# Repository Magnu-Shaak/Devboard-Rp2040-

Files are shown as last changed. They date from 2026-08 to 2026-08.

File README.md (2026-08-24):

# Devboard-Rp2040-

This is a devboard following the Kai Pereira tutorial. However, there are 2 major differences:
- 1: Mine breaks out all pins while following the Pi-Pico layout*(mostly). He followed the Pi-Pico layout too*, but I also added 2 1x2 connectors which I used to break out the final GPIO pin, and provide easy access to 3v3 and VBUS from the bottom of the board. This greatly benefits the left side, as it now has an ADC pin and power access from the bottom, instead of needing to run traces to the other side of the board. And despite moving the 3 pin connector (used for debugging) up, some Pi Pico boards have it in the center anyways, so this doesn't make in incompatible as a drop in replacement either(unless its battery operated).
- 2: I also have opted to use the higher power rated LDO for my 3v3 line, whereas he swapped to a lower power rated one for space. Just better overall.

I made these changes for convenience. Having a better LDO is generally just better and the ADC and power pin breakouts are really convenient and help reduce congestion below the chip.

*Replaced some unused i/o pins (VSYS, 3v3_EN, ADC_REF) to breakout some 3 more GPIO pins

## For Reproducing
If you are recreating this yourself, look at the Readme in production for more information.

BOM:
| Item |  Quantity | Listed Price | Total Cost [for me]  (shipping, sales tax) | Link | Source  | Notes |
|---|---|---|---|---|---|---|
| PCB | 5 | 2 | 2 | https://cart.jlcpcb.com/shopcart/cart | JLCPCB  | $2 deal |
| PCBA | 2 | 33.13 | 33.13 | https://cart.jlcpcb.com/shopcart/cart | JLCPCB  | |
| Custom Duties & Taxes | | 12.24 | 12.24 | https://cart.jlcpcb.com/shopcart/cart | JLCPCB  | US Customs |
| JLC Shipping (DDP) | | 29.98 | 29.98 | https://cart.jlcpcb.com/shopcart/cart | JLCPCB  | UPS Express (DDP)  |
| SMT PCBA Coupon | | -10 | -10 | https://cart.jlcpcb.com/shopcart/cart | JLC PCB | New Account Coupon |
| | | | | https://cart.jlcpcb.com/shopcart/cart | | |
| Total | 7 | 67.35 | 67.35 | https://excel.cloud.microsoft/en-us | | |

The extra connectors I added:



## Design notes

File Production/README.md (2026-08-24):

Creating Production folder

- Unzipped gerbers are under PCB

## For Production:

If you are RECREATING yourself, you need to EDIT the CPL FILE:
- U2: set rotation to 90*
- U3: set rotation to 270*
- J1: decrease Mid Y by 1.4605 mm

The files here are already edited, if you are having probelems.

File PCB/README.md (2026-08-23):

Creating PCB folder

 - Zipped gerbers are under Production

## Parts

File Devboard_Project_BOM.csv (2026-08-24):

Item | Quantity | Listed Price | Total Cost [for me] (shipping, sales tax) | Link | Source | Notes
PCB | 5 | 2 | 2 | https://cart.jlcpcb.com/shopcart/cart | JLCPCB | $2 deal
PCBA | 2 | 33.13 | 33.13 | https://cart.jlcpcb.com/shopcart/cart | JLCPCB
Custom Duties & taxes |  | 12.24 | 12.24 |  | JLCPCB | US Customs
JLC Shipping (DDP) |  | 29.98 | 29.98 |  | JLCPCB | UPS Express (DDP)
SMT PCBA Coupon |  | -10 | -10 |  | JLC PCB | New Account Coupon
Total | 7 | 67.35 | 67.35

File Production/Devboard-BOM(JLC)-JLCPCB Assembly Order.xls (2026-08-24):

JLCPCB BOM Tool - BOM Matching
BOM name：Devboard-BOM(JLC)-JLCPCB Assembly Order.xlsx |  |  | Download Time：2026-08-24 10:50:31 |  |  |  | * Our matching results are updated in real-time, but stock and prices may change. If it's been over 24 hours, please re-match before placing your order.
PCB Assembled Qty：5 |  |  | Est. Total Price：6.7236
Your BOM |  |  |  | Matched Parts |  |  |  |  |  |  | Order Information
Designator | Comment | Footprint | JLCPCB Part # | Matches | Part # | Manufacturer | Footprint | Description | Category | Warning | JLCPCB Part # | Product link | Lib Type | Qty | Source | Total Price ($)
C1,C10 | 1uF | Capacitor_SMD:C_0402_1005Metric |  | Select by System | CL05A105KA5NQNC | Samsung Electro-Mechanics | 0402 | 1uF 25V X5R ±10% 0402 Multilayer Ceramic Capacitors MLCC - SMD/SMT ROHS | Multilayer Ceramic Capacitors MLCC - SMD/SMT |  | C52923 | https://jlcpcb.com/partdetail/53938-CL05A105KA5NQNC/C52923 | Basic | 4 | 4 JLCPCB | 0.0484
C2,C3,C4,C5,C6,C7,C8,C9,C11,C12,C17 | 0.1uF | Capacitor_SMD:C_0402_1005Metric |  | Select by System | CL05B104KO5NNNC | Samsung Electro-Mechanics | 0402 | 100nF 16V X7R ±10% 0402 Multilayer Ceramic Capacitors MLCC - SMD/SMT ROHS | Multilayer Ceramic Capacitors MLCC - SMD/SMT |  | C1525 | https://jlcpcb.com/partdetail/1877-CL05B104KO5NNNC/C1525 | Basic | 22 | 22 JLCPCB | 0.121
C13,C14 | 10uF | Capacitor_SMD:C_0603_1608Metric |  | Select by System | CL10A106KP8NNNC | Samsung Electro-Mechanics | 0603 | 10V 10uF X5R ±10% 0603 Multilayer Ceramic Capacitors MLCC - SMD/SMT ROHS | Multilayer Ceramic Capacitors MLCC - SMD/SMT |  | C19702 | https://jlcpcb.com/partdetail/20411-CL10A106KP8NNNC/C19702 | Basic | 4 | 4 JLCPCB | 0.1452
C15,C16 | 33pF | Capacitor_SMD:C_0402_1005Metric |  | Select by System | 0402CG330J500NT | FH (Guangdong Fenghua Advanced Tech) | 0402 | 33pF 50V C0G ±5% 0402 Multilayer Ceramic Capacitors MLCC - SMD/SMT ROHS | Multilayer Ceramic Capacitors MLCC - SMD/SMT |  | C1562 | https://jlcpcb.com/partdetail/1914-0402CG330J500NT/C1562 | Basic | 4 | 4 JLCPCB | 0.0228
J1 | USB_C_Receptacle_USB2.0_14P | Connector_USB:USB_C_Receptacle_HRO_TYPE-C-31-M-12 |  | Select by System | TYPE-C-31-M-12 | Korean Hroparts Elec | SMD | -30℃~+80℃ 1 10,000 cycles 16P 20V 5A 7.35mm Female Surface Mount, Right Angle Type-C SMD USB Connectors ROHS | USB Connectors |  | C165948 | https://jlcpcb.com/partdetail/Korean_HropartsElec-TYPE_C_31_M12/C165948 | Extended | 2 | 2 JLCPCB | 0.371
J2,J3 | Conn_01x20 | Connector_PinHeader_2.54mm:PinHeader_1x20_P2.54mm_Vertical |  | Select by System | 2.54-1*20P直针 | BOOMELE(Boom Precision Elec) | 插件,P=2.54mm | -40℃~+105℃ 1 1x20P 2.54mm 20P 3A Black Brass Pin Header Through Hole 插件,P=2.54mm Pin Headers ROHS | Pin Headers |  | C50981 | https://jlcpcb.com/partdetail/51993-2_54_1_20P/C50981 | Extended | 0 | 0 JLCPCB | 0
J4 | Conn_01x03 | Connector_PinHeader_2.54mm:PinHeader_1x03_P2.54mm_Vertical |  | Select by System | 1.27-1*3P针 | BOOMELE(Boom Precision Elec) | 插件,P=1.27mm | -55℃~+105℃ 1 1.27mm 1.7mm 1x3P 2.5mm 3A 3P 3mm Black Brass Pin Header Through Hole 插件,P=1.27mm Pin Headers ROHS | Pin Headers |  | C24980 | https://jlcpcb.com/partdetail/25717-1_27_1_3P/C24980 | Extended | 0 | 0 JLCPCB | 0
J5,J6 | Conn_01x02 | Connector_PinHeader_2.54mm:PinHeader_1x02_P2.54mm_Vertical |  | Select by System | PZ254V-11-02P | XFCN | 插件,P=2.54mm | -40℃~+105℃ 1 1x2P 2.54mm 2.5mm 250V 2P 3A 3mm 6mm Black Brass Pin Header Through Hole 插件,P=2.54mm Pin Headers ROHS | Pin Headers |  | C492401 | https://jlcpcb.com/partdetail/XFCN-PZ254V_1102P/C492401 | Extended | 0 | 0 JLCPCB | 0
R1,R2 | 5.1K | Resistor_SMD:R_0402_1005Metric |  | Select by System | 0402WGF5101TCE | UNI-ROYAL(Uniroyal Elec) | 0402 | -55℃~+155℃ 5.1kΩ 50V 62.5mW Thick Film Resistor ±1% ±100ppm/℃ 0402 Chip Resistor - Surface Mount ROHS | Chip Resistor - Surface Mount |  | C25905 | https://jlcpcb.com/partdetail/26648-0402WGF5101TCE/C25905 | Basic | 4 | 4 JLCPCB | 0.0172
R3,R4 | 27 | Resistor_SMD:R_0402_1005Metric |  | Select by System | 0402WGF270JTCE | UNI-ROYAL(Uniroyal Elec) | 0402 | -55℃~+155℃ 27Ω 50V 62.5mW Thick Film Resistor ±1% ±100ppm/℃ 0402 Chip Resistor - Surface Mount ROHS | Chip Resistor - Surface Mount |  | C25100 | https://jlcpcb.com/partdetail/25843-0402WGF270JTCE/C25100 | Extended | 20 | 20 JLCPCB | 0.064
R5,R6 | 1K | Resistor_SMD:R_0402_1005Metric |  | Select by System | 0402WGF1001TCE | UNI-ROYAL(Uniroyal Elec) | 0402 | -55℃~+155℃ 1kΩ 50V 62.5mW Thick Film Resistor ±1% ±100ppm/℃ 0402 Chip Resistor - Surface Mount ROHS | Chip Resistor - Surface Mount |  | C11702 | https://jlcpcb.com/partdetail/12256-0402WGF1001TCE/C11702 | Basic | 4 | 4 JLCPCB | 0.0268
R7 | 10K | Resistor_SMD:R_0402_1005Metric |  | Select by System | 0402WGF1002TCE | UNI-ROYAL(Uniroyal Elec) | 0402 | -55℃~+155℃ 10kΩ 50V 62.5mW Thick Film Resistor ±1% ±100ppm/℃ 0402 Chip Resistor - Surface Mount ROHS | Chip Resistor - Surface Mount |  | C25744 | https://jlcpcb.com/partdetail/26487-0402WGF1002TCE/C25744 | Basic | 2 | 2 JLCPCB | 0.0038
SW1 | SW_Push | Button_Switch_SMD:SW_Push_SPST_NO_Alps_SKRK |  | Select by System | TS-1088-AR02016 | XUNPU | SMD,4x3mm | -30℃~+80℃ 1.6N 100,000 cycles 12V 2mm 3.9mm 3mm 50mA Black Round Button SMD(SMT) Tab SPST Surface Mount,Vertical Without Bracket SMD,4x3mm Tactile Switches ROHS | Tactile Switches |  | C720477 | https://jlcpcb.com/partdetail/XUNPU-TS_1088AR02016/C720477 | Basic | 2 | 2 JLCPCB | 0.1112
U1 | RP2040 | Package_DFN_QFN:QFN-56-1EP_7x7mm_P0.4mm_EP3.2x3.2mm |  | Select by System | RP2040 | Raspberry Pi | LQFN-56(7x7) | 12bit 133MHz 30 LQFN-56(7x7) Microcontrollers (MCU/MPU/SOC) ROHS | Microcontrollers (MCU/MPU/SOC) |  | C2040 | https://jlcpcb.com/partdetail/RaspberryPi-RP2040/C2040 | Extended | 2 | 2 JLCPCB | 1.9846
U2 | NCP1117-3.3_SOT223 | Package_TO_SOT_SMD:SOT-223-3_TabPin2 |  | Select by System | NCP1117ST33T3G | onsemi | SOT-223 | 0.003%Vout 0℃~+125℃@(Ta) 1 1.2V@(800mA) 1A 20V 3.3V 62dB@(120Hz) 6mA Fixed Over Current Protection、Thermal Shutdown Positive SOT-223 Voltage Regulators - Linear, Low Drop Out (LDO) Regulators ROHS | Voltage Regulators - Linear, Low Drop Out (LDO) Regulators |  | C26537 | https://jlcpcb.com/partdetail/onsemi-NCP1117ST33T3G/C26537 | Extended | 2 | 2 JLCPCB | 0.4708
U3 | W25Q16JVUXIQTR | Package_SON:Winbond_USON-8-1EP_3x2mm_P0.5mm_EP0.2x1.6mm |  | Select by System | W25Q16JVUXIQ | Winbond Elec | USON-8-EP(2x3) | -40℃~+85℃ 100,000 cycles 10uA 133MHz 16Mbit 2.7V~3.6V 20 Years 3ms SPI USON-8-EP(2x3) NOR FLASH ROHS | NOR FLASH |  | C2843335 | https://jlcpcb.com/partdetail/WinbondElec-W25Q16JVUXIQ/C2843335 | Extended | 2 | 2 JLCPCB | 3.1474
Y1 | 12MHz | Crystal:Crystal_SMD_3225-4Pin_3.2x2.5mm |  | Select by System | X322512MSB4SI | YXC Crystal Oscillators | SMD3225-4P | -40℃~+85℃ 12MHz 20pF 80Ω Crystal Oscillator ±10ppm ±20ppm SMD3225-4P Crystals ROHS | Crystals |  | C9002 | https://jlcpcb.com/partdetail/YXC_CrystalOscillators-X322512MSB4SI/C9002 | Basic | 2 | 2 JLCPCB | 0.1894

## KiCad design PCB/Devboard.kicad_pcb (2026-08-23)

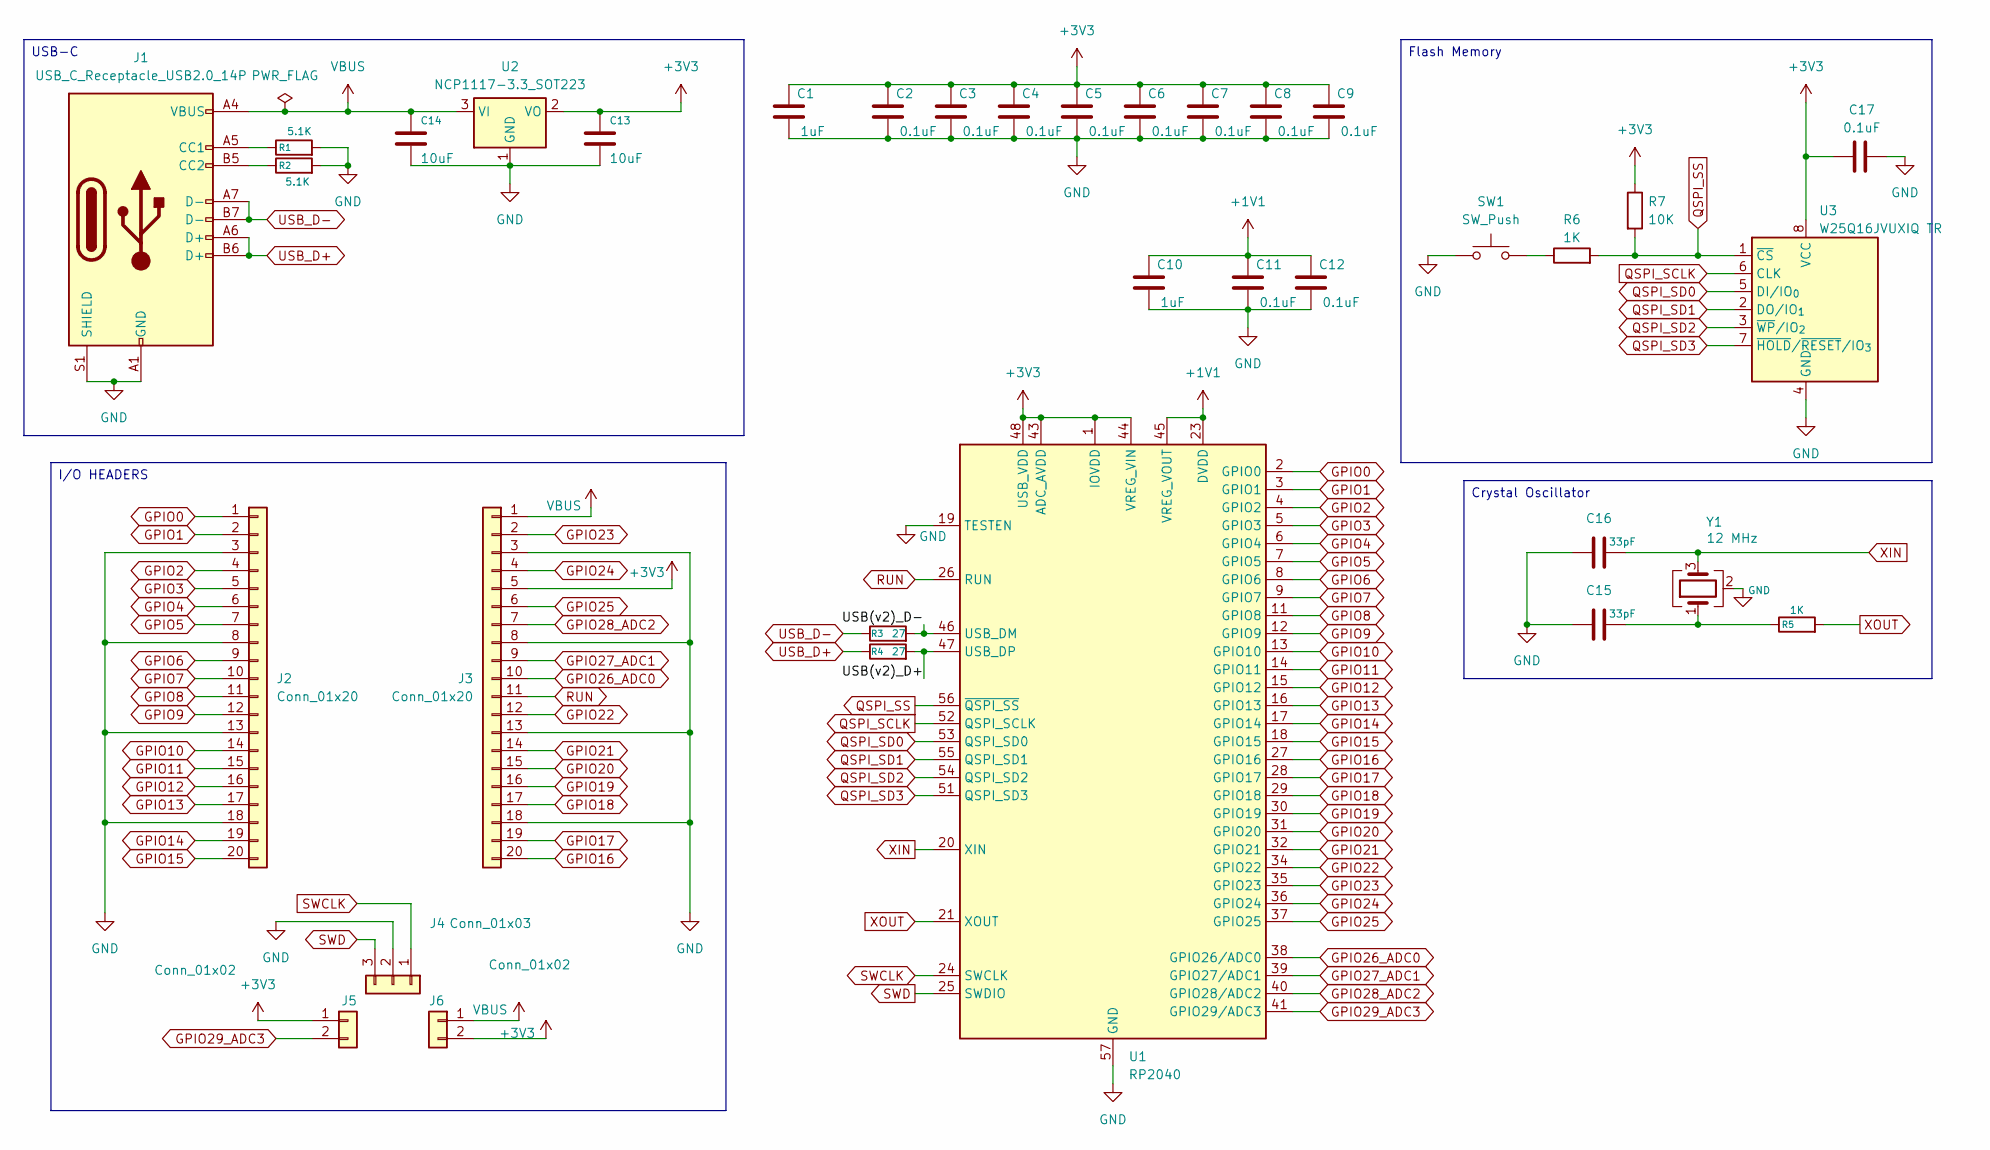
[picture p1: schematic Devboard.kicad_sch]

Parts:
C1, C10: 1uF; C_0402_1005Metric
C2, C3, C4, C5, C6, C7, C8, C9, C11, C12, C17: 0.1uF; C_0402_1005Metric
C13, C14: 10uF; C_0603_1608Metric
C15, C16: 33pF; C_0402_1005Metric
J1: USB_C_Receptacle_USB2.0_14P; USB_C_Receptacle_HRO_TYPE-C-31-M-12
J2, J3: Conn_01x20; PinHeader_1x20_P2.54mm_Vertical
J4: Conn_01x03; PinHeader_1x03_P2.54mm_Vertical
J5, J6: Conn_01x02; PinHeader_1x02_P2.54mm_Vertical
R1, R2: 5.1K; R_0402_1005Metric
R3, R4: 27; R_0402_1005Metric
R5, R6: 1K; R_0402_1005Metric
R7: 10K; R_0402_1005Metric
SW1: SW_Push; SW_Push_SPST_NO_Alps_SKRK
U1: RP2040; QFN-56-1EP_7x7mm_P0.4mm_EP3.2x3.2mm
U2: NCP1117-3.3_SOT223; SOT-223-3_TabPin2
U3: W25Q16JVUXIQ TR; Winbond_USON-8-1EP_3x2mm_P0.5mm_EP0.2x1.6mm
Y1: 12 MHz; Crystal_SMD_3225-4Pin_3.2x2.5mm

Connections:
+1V1: C10.1, C11.1, C12.1, U1.23 (DVDD), U1.45 (VREG_VOUT), U1.50 (DVDD)
+3V3: C1.1, C2.1, C3.1, C4.1, C5.1, C6.1, C7.1, C8.1, C9.1, C13.1, C17.1, J3.5, J5.1, J6.2, R7.1, U1.1 (IOVDD), U1.10 (IOVDD), U1.22 (IOVDD), U1.33 (IOVDD), U1.42 (IOVDD), U1.43 (ADC_AVDD), U1.44 (VREG_VIN), U1.48 (USB_VDD), U1.49 (IOVDD), U2.2 (VO), U3.8 (VCC)
/USB(v2)_D+: R4.2, U1.47 (USB_DP)
/USB(v2)_D-: R3.2, U1.46 (USB_DM)
GND: C1.2, C2.2, C3.2, C4.2, C5.2, C6.2, C7.2, C8.2, C9.2, C10.2, C11.2, C12.2, C13.2, C14.2, C15.1, C16.1, C17.2, J1.A1 (GND), J1.A12 (GND), J1.B1 (GND), J1.B12 (GND), J1.S1 (SHIELD), J2.3, J2.8, J2.13, J2.18, J3.3, J3.8, J3.13, J3.18, J4.2, R1.2, R2.2, SW1.1, U1.19 (TESTEN), U1.57 (GND), U2.1 (GND), U3.4 (GND), Y1.2 (G), Y1.4 (G)
GPIO0: J2.1, U1.2 (GPIO0)
GPIO1: J2.2, U1.3 (GPIO1)
GPIO2: J2.4, U1.4 (GPIO2)
GPIO3: J2.5, U1.5 (GPIO3)
GPIO4: J2.6, U1.6 (GPIO4)
GPIO5: J2.7, U1.7 (GPIO5)
GPIO6: J2.9, U1.8 (GPIO6)
GPIO7: J2.10, U1.9 (GPIO7)
GPIO8: J2.11, U1.11 (GPIO8)
GPIO9: J2.12, U1.12 (GPIO9)
GPIO10: J2.14, U1.13 (GPIO10)
GPIO11: J2.15, U1.14 (GPIO11)
GPIO12: J2.16, U1.15 (GPIO12)
GPIO13: J2.17, U1.16 (GPIO13)
GPIO14: J2.19, U1.17 (GPIO14)
GPIO15: J2.20, U1.18 (GPIO15)
GPIO16: J3.20, U1.27 (GPIO16)
GPIO17: J3.19, U1.28 (GPIO17)
GPIO18: J3.17, U1.29 (GPIO18)
GPIO19: J3.16, U1.30 (GPIO19)
GPIO20: J3.15, U1.31 (GPIO20)
GPIO21: J3.14, U1.32 (GPIO21)
GPIO22: J3.12, U1.34 (GPIO22)
GPIO23: J3.2, U1.35 (GPIO23)
GPIO24: J3.4, U1.36 (GPIO24)
GPIO25: J3.6, U1.37 (GPIO25)
GPIO26_ADC0: J3.10, U1.38 (GPIO26/ADC0)
GPIO27_ADC1: J3.9, U1.39 (GPIO27/ADC1)
GPIO28_ADC2: J3.7, U1.40 (GPIO28/ADC2)
GPIO29_ADC3: J5.2, U1.41 (GPIO29/ADC3)
unnamed: C15.2, R5.1, Y1.1
unnamed: J1.A5 (CC1), R1.1
unnamed: J1.B5 (CC2), R2.1
unnamed: R6.1, SW1.2
QSPI_SCLK: U1.52 (QSPI_SCLK), U3.6 (CLK)
QSPI_SD0: U1.53 (QSPI_SD0), U3.5 (DI/IO_{0})
QSPI_SD1: U1.55 (QSPI_SD1), U3.2 (DO/IO_{1})
QSPI_SD2: U1.54 (QSPI_SD2), U3.3 (~WP/IO_{2})
QSPI_SD3: U1.51 (QSPI_SD3), U3.7 (~HOLD/~RESET/IO_{3})
QSPI_SS: R6.2, R7.2, U1.56 (~QSPI_SS), U3.1 (~CS)
RUN: J3.11, U1.26 (RUN)
SWCLK: J4.1, U1.24 (SWCLK)
SWD: J4.3, U1.25 (SWDIO)
USB_D+: J1.A6 (D+), J1.B6 (D+), R4.1
USB_D-: J1.A7 (D-), J1.B7 (D-), R3.1
VBUS: C14.1, J1.A4 (VBUS), J1.A9 (VBUS), J1.B4 (VBUS), J1.B9 (VBUS), J3.1, J6.1, U2.3 (VI)
XIN: C16.2, U1.20 (XIN), Y1.3
XOUT: R5.2, U1.21 (XOUT)

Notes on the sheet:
Flash Memory
Crystal Oscillator
I/O HEADERS
USB-C

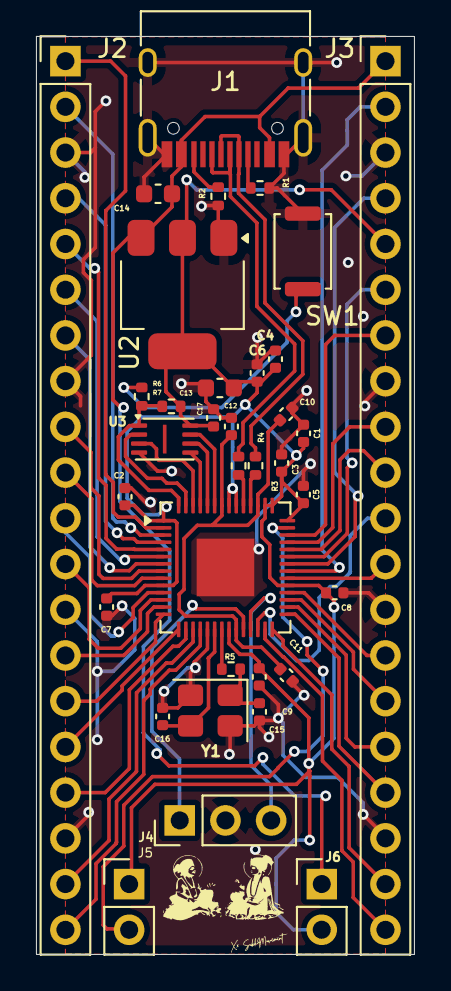
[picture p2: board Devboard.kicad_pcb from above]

Board: 2 copper layers, 21.0 x 51.0 mm, 35 parts (0 on the bottom side), 53 nets.

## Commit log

2026-08-23 Add Kicad PCB files
    [Devboard.kicad_pcb, Devboard.kicad_sch]
2026-08-23 Add gerber files
    [Devboard-B_Cu.gbr, Devboard-B_Mask.gbr, Devboard-B_Paste.gbr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]
2026-08-23 Add gerbers zip file
2026-08-23 Add BOM and CPL files
    [Devboard-BOM(JLC)-JLCPCB Assembly Order.xls, Devboard-BOM(JLC).csv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]
